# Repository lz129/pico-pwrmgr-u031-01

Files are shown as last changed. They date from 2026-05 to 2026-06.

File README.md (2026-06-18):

# Bluetooth LE based Remote Control Transmitter

What is it? A replacement for broken remote controls used for garage doors and similar purposes. Original equipment is often expensive or completely unobtainium.

Board in housing

## Versions

This document describes rev A. The design and the PCB have some [issues](ISSUES.md) which requires hardware patches on the PCB.

## Hardware

The major part is a [Raspberry Pi Pico W](https://pip-assets.raspberrypi.com/categories/686-raspberry-pi-pico-w/documents/RP-008312-DS-1-pico-w-datasheet.pdf) which is responsible to handle the Bluetooth LE protocol. In order to handle the low power mode of the device an additional microcontroller is used.

The board has been designed with Kicad 10. For details refer to 
[Schematic](bt-rc-tx/schematic.pdf), [PCB](bt-rc-tx/board.pdf), and [PCB-3d](bt-rc-tx/board-3d.png).

Fixes required on the PCB rev A:

* The decoupling capacitor C2 for the microcontroller shall be changed from 100n to 10u. 

* Parallel to C1 an additional electrolyte cap with 470u has to be connected.

* Pin 39 of the Raspberry Pi Pico W has to be disconnected from the +BATT network and a jumper Jx has to be added.

Modifications required on the Raspberry Pi Pico W board:

* Remove R2 and R10 ([power circuit Pico W](images/power-circuit-pico-w.png))

Refer to [images](images) for details.

|Image|Content|
|-----|---|
|[Shipping box](images/shipping-box.jpg)|PCBs as delivered by JLCPCB|
|[Delivered boards](images/delivered-boards.jpg)|PCBs as delivered by JLCPCB|
|[Board unpopulated (front)](images/board-unpopulated-front.jpg)|The unpopulated PCB from the top side|
|[Board unpopulated (back)](images/board-unpopulated-back.jpg)|The unpopulated PCB from the back side|
|[Breadboard setup](images/breadboard-setup.jpg)|The complete design on a breadboard|
|[Debug connections (front)](images/debug-connections-front.jpg)|Populated PCB with debug connections (front)|
|[Debug connections (back)](images/debug-connections-back.jpg)|Populated PCB with debug connections (back)|
|[Board in housing](images/board-in-housing.jpg)|Populated PCB in housing|
|[Final device with batteries](images/final-device-open-box.jpg)|Final device with batteries and open housing|

## Software

### Power Controller

The power controller, a STM32U031 microcontroller handles power up and power down of the Raspberry Pi Pico W, reads keyboard input and controls the LEDs. When completely powered down the transmitter draws only approx. 400nA from the Batteries.

The power controller shuts down the Raspi automatically after a given time (currently 10s) in case the Python script does not complete for whatever reason. The script is able to send a signal over GPIO to the power controller to request an immediate shutdown after its job has finished.

To assist development the power controller can be switched to a debug mode where the Raspberry Pi is powered without timeout. This mode shall be used for Python script development. The mode can be activated by pressing button A for more than 3s. Press button A again to leave the debug mode.

Another debug and test aid is the inhibit power down jumper J4. When active the power controller does not go into power down mode but behaves otherwise identical. Use this jumper when debugging the power controller with ST-Link.

__Note:__ Powering the Raspberry Pi Pico W without timeout is only possible when the jumper J4 is set.

__IMPORTANT:__ The jumper J5 (currently not in rev A design) MUST be removed when connecting the Raspberry Pi Pico W via USB cable to a PC. The cable would supply the power controller with the USB bus voltage of 5V. The power controller however is a 3.3V device which can be damaged in this mode. Instead connect the battery or a lab power supply with 3.3V to supply the power controller.

### Raspberry Pi Pico W

Timing and performance is not critical in the application. Therefore a solution with [Micropython](https://micropython.org) has been chosen. Prebuilt versions for the Raspberry Pi Pico W are available [here](https://micropython.org/download/RPI_PICO_W/). Installation of the Python system can be easily done without tools unsing the UF2 bootloader.

The current python [script](python/garagedoor_central.py) is minimalistic at this time and can be extended as necessary to add additional features.

__Attention__: The sample script has no means for secure communication!

### Connectors and Jumpers

All connectors and jumpers are located on the back side of the PCB.

__J1__ is the connector for the battery. The transmitter is designed to operate on two AA or AAA cells. Both alkali mangan and NiMH cells can be used. Note that the voltage range is dicated by the microcontroller which operates on 1.71 to 3.6 volts and the buck/boost converter in the Raspberry Pi Pico W module which accepts 1.8 to 5.5 volts. Therefore the effective voltage range is between 1.8 and 3.6 volts.

__J3__ is a debug connector to attach a debug probe like the ST-Link from ST Microelectronics. The pin assignment is as follows:

|Pin|Purpose|Comments|
|---|---|---|
|1|GND|
|2|VCC|This is a sense wire for the debug probe to handle the voltage levels correctly. Do not provide power on this pin!|
|3|SWDIO|Serial Wire Debug data I/O 
|4|SWCLK|Serial Wire Debug clock
|5|/Reset|Reset controller

__J5__ jumper to inhibit shutdown. Use it when debugging to avoid debug probe disconnect due to powering down the chip. For normal operation and low power while not using the device the jumper has to be removed.

__Jx__ jumper patched into the rev A design. It disconnects the incoming power from the USB to the microcontroller. __The microcontroller can be damaged when an USB cable is connected to the Raspberry Pi board and the jumper is not removed.__

# BOM

|Reference|Qty|Value|DNP|Exclude from BOM|Exclude from Board|Footprint|Datasheet|
|---|---|-----|---|---|---|---|----|
|A1|1|RaspberryPi_Pico_W||||Module:RaspberryPi_Pico_W_SMD_HandSolder|https://datasheets.raspberrypi.com/picow/pico-w-datasheet.pdf|
|C1|1|47u||||Capacitor_SMD:C_1206_3216Metric|
|C2|1|100n||||Capacitor_SMD:C_0805_2012Metric|
|D3|1|LED1||||LED_THT:LED_D5.0mm|
|D4|1|LED2||||LED_THT:LED_D5.0mm|
|J1|1|Battery 3V||||Connector_PinHeader_2.54mm:PinHeader_1x02_P2.54mm_Horizontal|
|J3|1|SW Debug||||Connector_PinHeader_2.54mm:PinHeader_1x05_P2.54mm_Horizontal|
|J4|1|Inhibit Shutdown||||Connector_PinHeader_2.54mm:PinHeader_1x02_P2.54mm_Horizontal|
|R4,R5|2|2k2||||Resistor_SMD:R_0805_2012Metric|
|SW2|1|BUTTON1||||Button_Switch_THT:SW_PUSH_6mm|
|SW3|1|BUTTON2||||Button_Switch_THT:SW_PUSH_6mm|
|U2|1|STM32U031F8Px||||Package_SO:TSSOP-20_4.4x6.5mm_P0.65mm|https://www.st.com/resource/en/datasheet/stm32u031f8.pdf|
||1|STRAPUBOX 6062 GR Plastic Box 85x65x28mm|||x|Housing|
|Cx|1|470u||||Aluminium Elko radial|

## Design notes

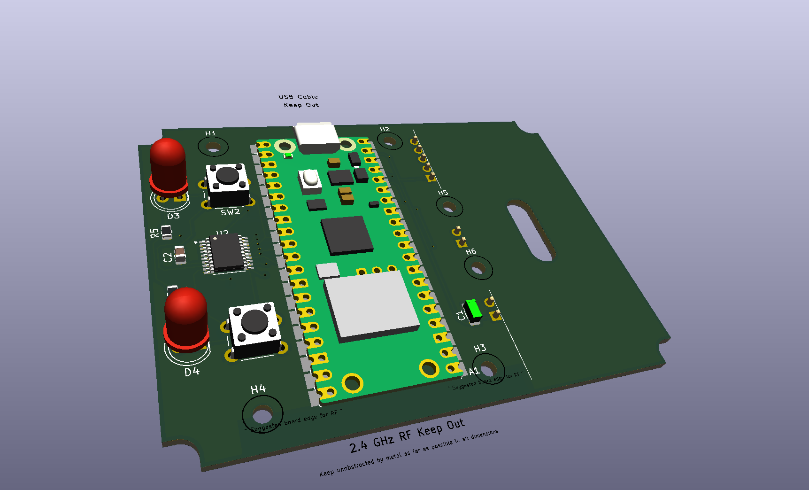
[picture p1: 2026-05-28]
bt-rc-tx/bt-rc-tx.png

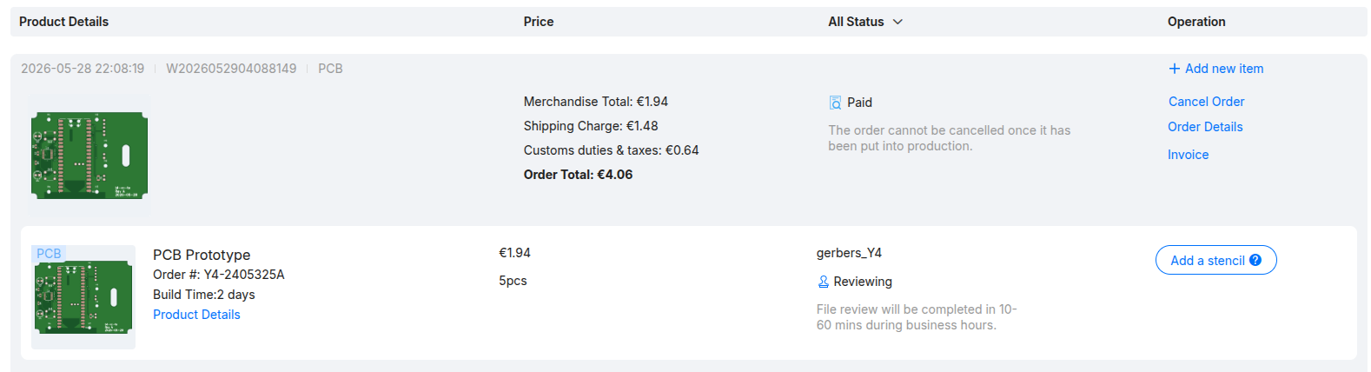
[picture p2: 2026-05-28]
bt-rc-tx/gerbers/ksnip_20260528-221821.png

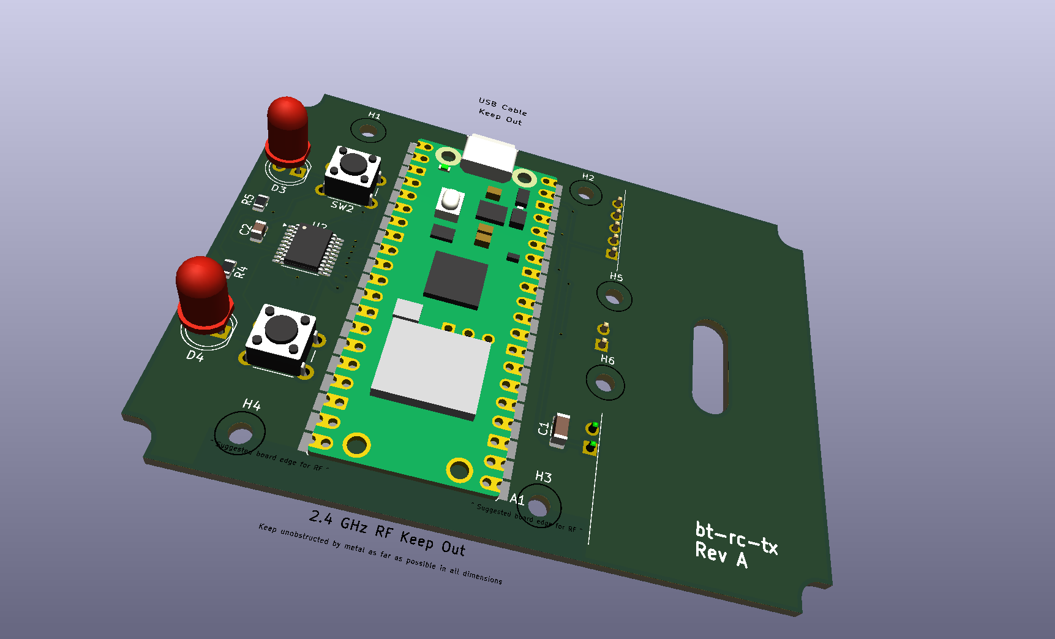
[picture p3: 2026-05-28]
bt-rc-tx/board-3d.png

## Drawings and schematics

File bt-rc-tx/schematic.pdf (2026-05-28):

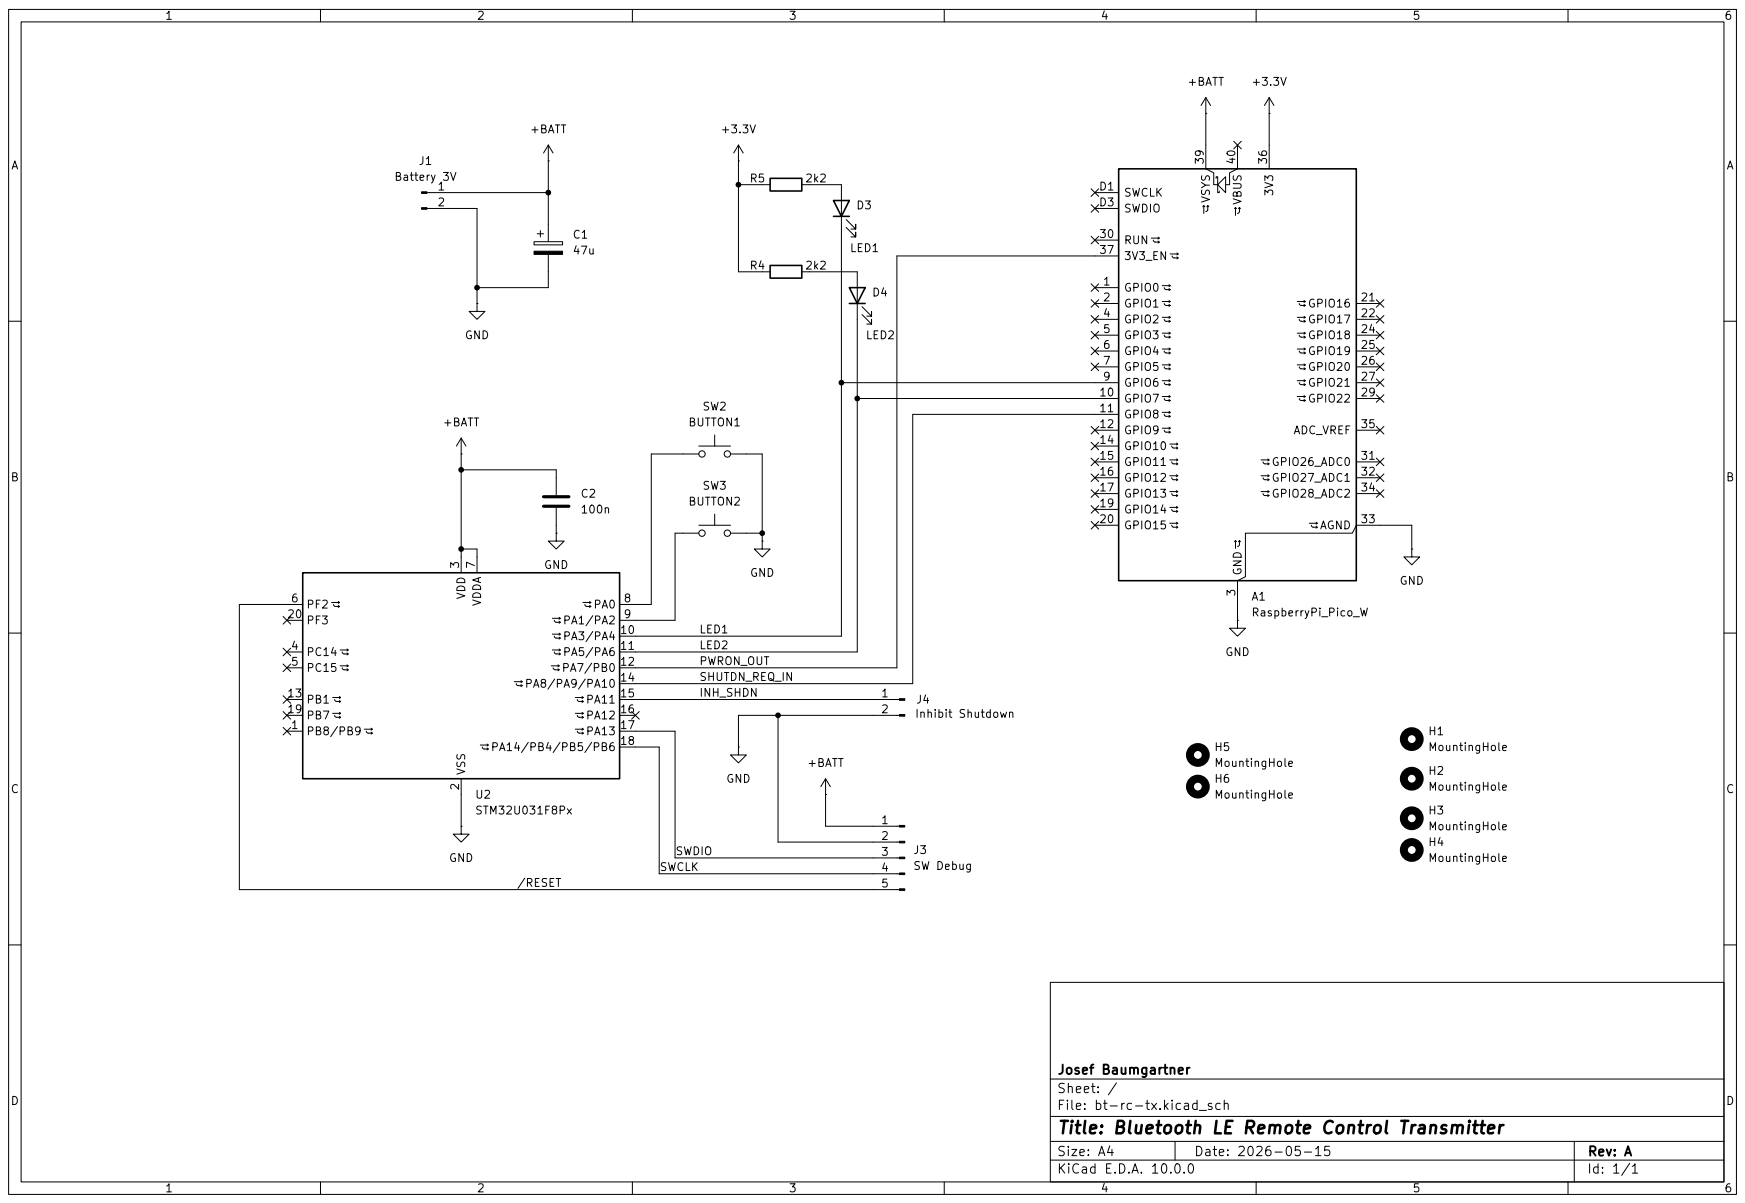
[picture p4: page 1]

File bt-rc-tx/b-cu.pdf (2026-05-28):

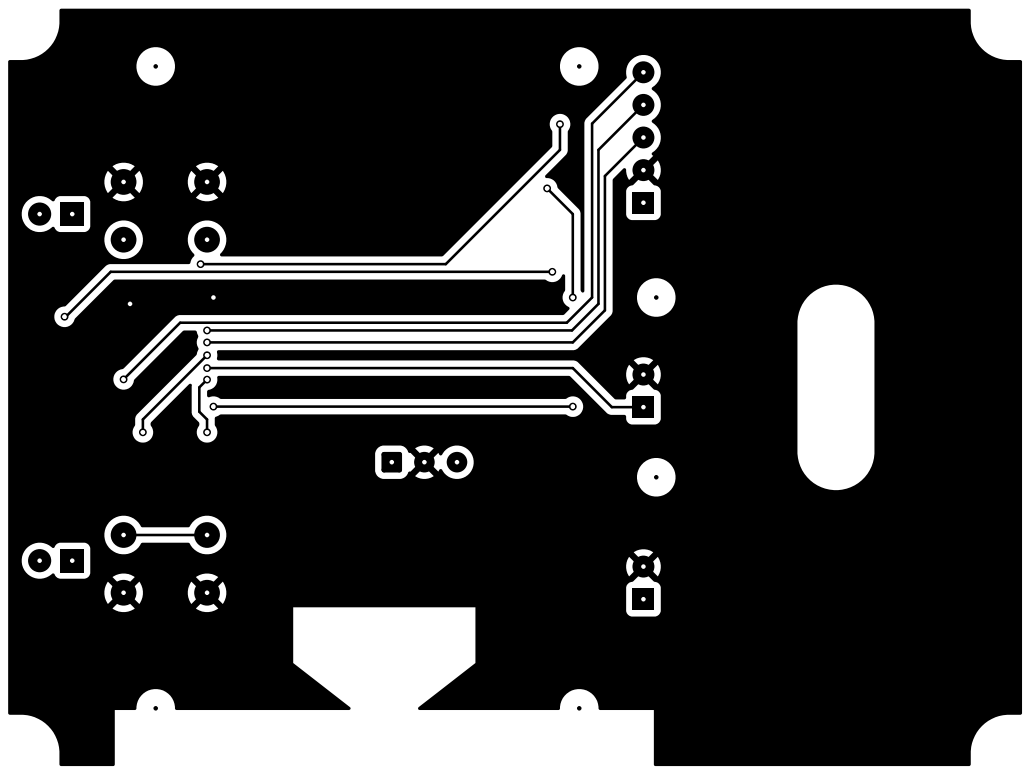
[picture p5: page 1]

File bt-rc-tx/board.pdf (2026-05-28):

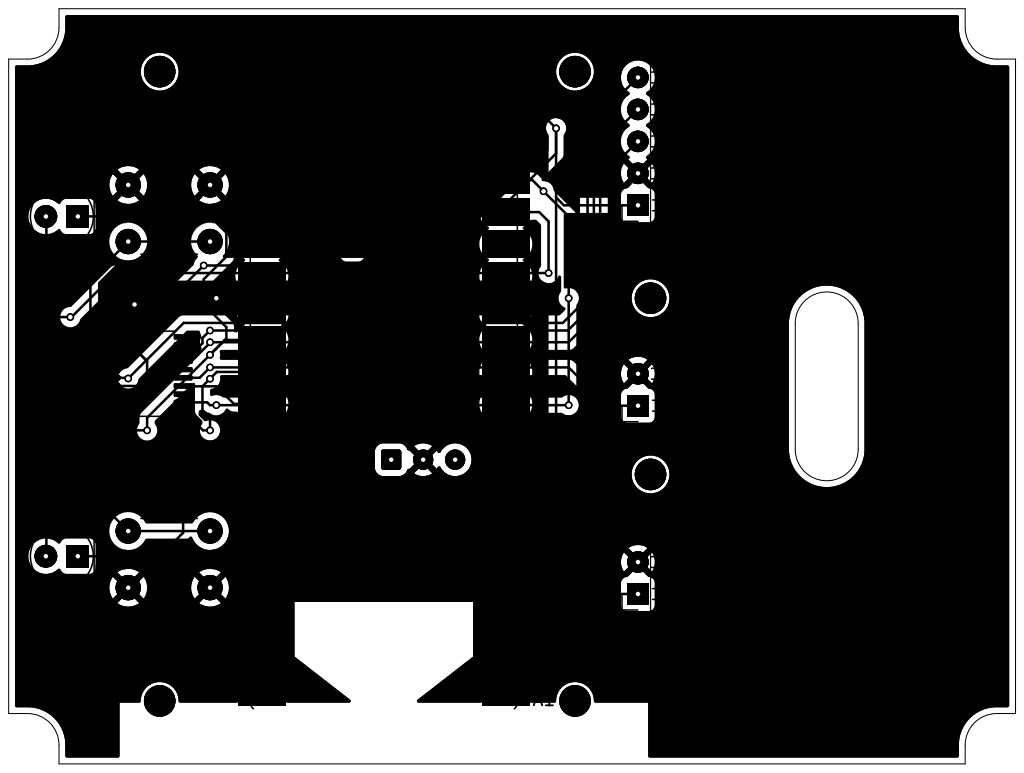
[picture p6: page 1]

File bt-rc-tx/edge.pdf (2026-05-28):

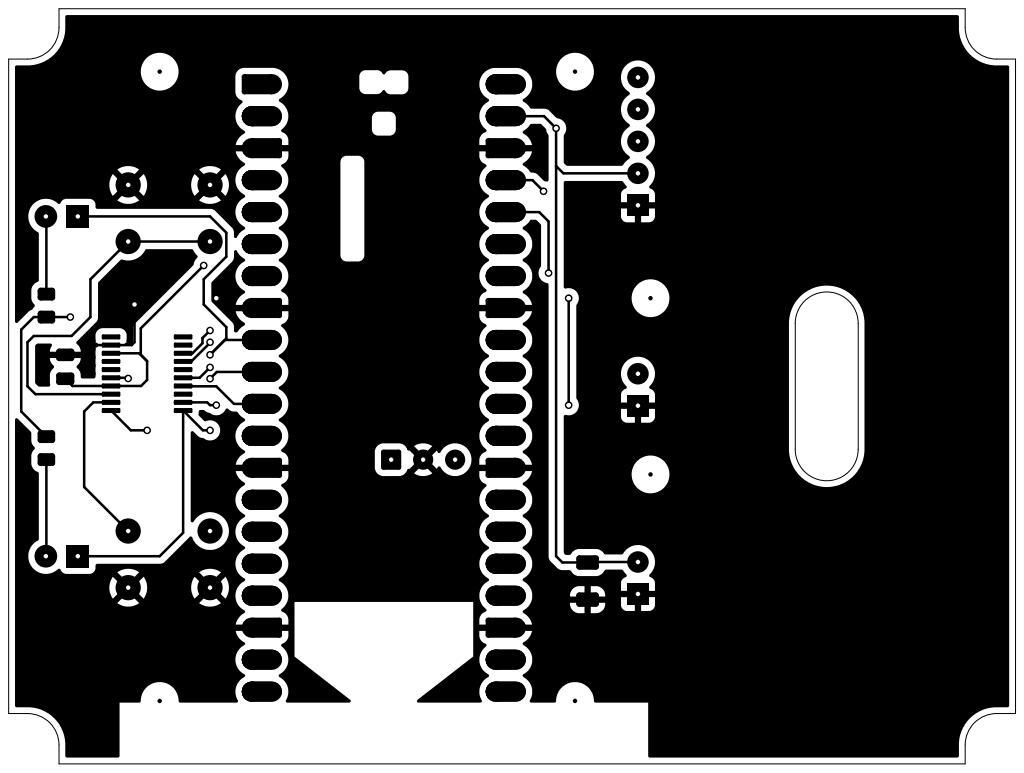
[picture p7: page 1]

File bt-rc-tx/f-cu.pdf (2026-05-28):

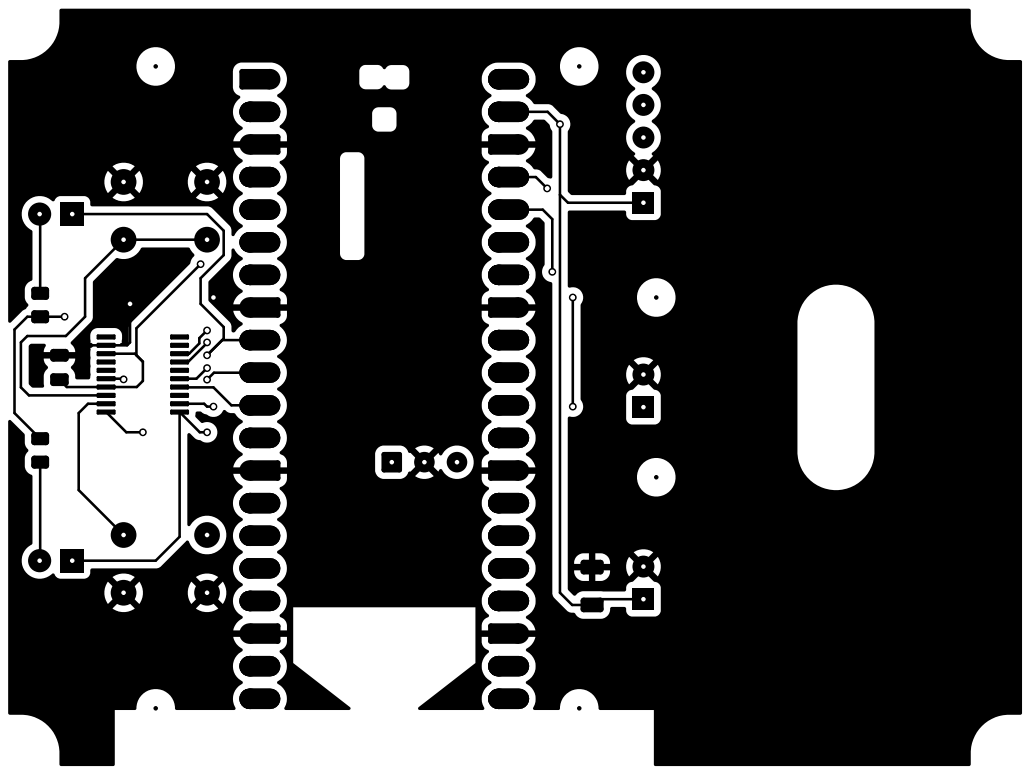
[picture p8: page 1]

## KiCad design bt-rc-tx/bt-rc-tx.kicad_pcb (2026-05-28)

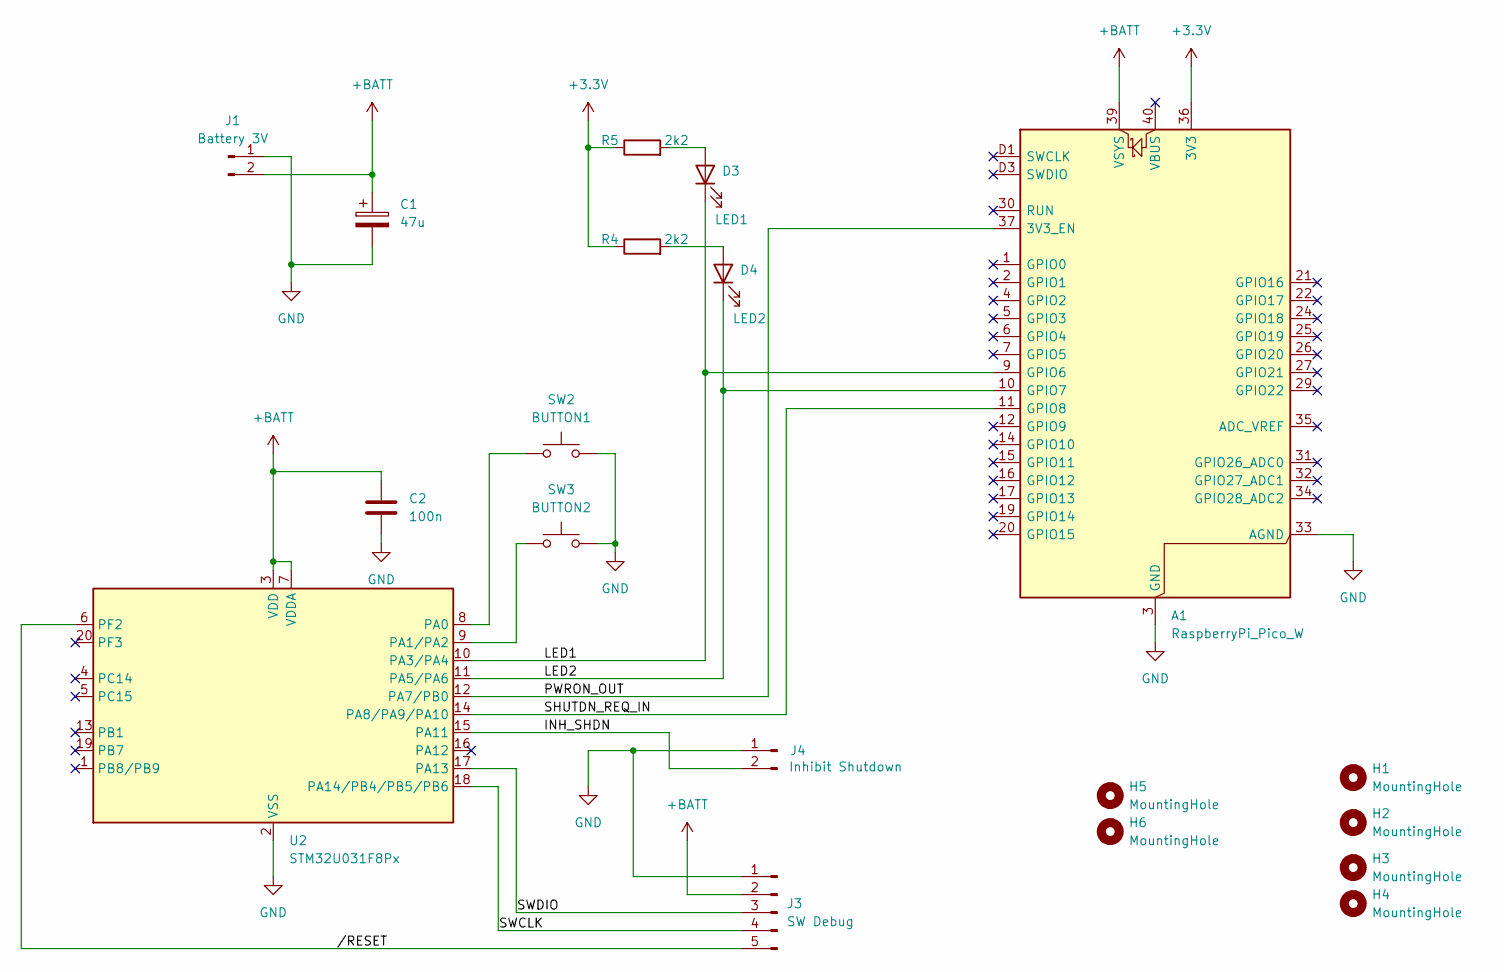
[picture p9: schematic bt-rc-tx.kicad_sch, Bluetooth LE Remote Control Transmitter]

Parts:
A1: RaspberryPi_Pico_W; RaspberryPi_Pico_W_SMD_HandSolder
C1: 47u; C_1206_3216Metric
C2: 100n; C_0805_2012Metric
D3: LED1; LED_D5.0mm
D4: LED2; LED_D5.0mm
H1, H2, H3, H4, H5, H6: MountingHole; MountingHole_2.5mm
J1: Battery 3V; PinHeader_1x02_P2.54mm_Horizontal
J3: SW Debug; PinHeader_1x05_P2.54mm_Horizontal
J4: Inhibit Shutdown; PinHeader_1x02_P2.54mm_Horizontal
R4, R5: 2k2; R_0805_2012Metric
SW2: BUTTON1; SW_PUSH_6mm
SW3: BUTTON2; SW_PUSH_6mm
U2: STM32U031F8Px; TSSOP-20_4.4x6.5mm_P0.65mm

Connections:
+3.3V: A1.36 (3V3), R4.1, R5.1
+BATT: A1.39 (VSYS), C1.1, C2.1, J1.2, J3.2, U2.3 (VDD), U2.7 (VDDA)
/INH_SHDN: J4.2, U2.15 (PA11)
/LED1: A1.9 (GPIO6), D3.1 (K), U2.10 (PA3/PA4)
/LED2: A1.10 (GPIO7), D4.1 (K), U2.11 (PA5/PA6)
/PWRON_OUT: A1.37 (3V3_EN), U2.12 (PA7/PB0)
/SHUTDN_REQ_IN: A1.11 (GPIO8), U2.14 (PA8/PA9/PA10)
/SWCLK: J3.4, U2.18 (PA14/PB4/PB5/PB6)
/SWDIO: J3.3, U2.17 (PA13)
//RESET: J3.5, U2.6 (PF2)
GND: A1.3 (GND), A1.8 (GND), A1.13 (GND), A1.18 (GND), A1.23 (GND), A1.28 (GND), A1.33 (AGND), A1.38 (GND), A1.D2 (GND), C1.2, C2.2, J1.1, J3.1, J4.1, SW2.2, SW3.2, U2.2 (VSS)
unnamed: D3.2 (A), R5.2
unnamed: D4.2 (A), R4.2
unnamed: SW2.1, U2.8 (PA0)
unnamed: SW3.1, U2.9 (PA1/PA2)

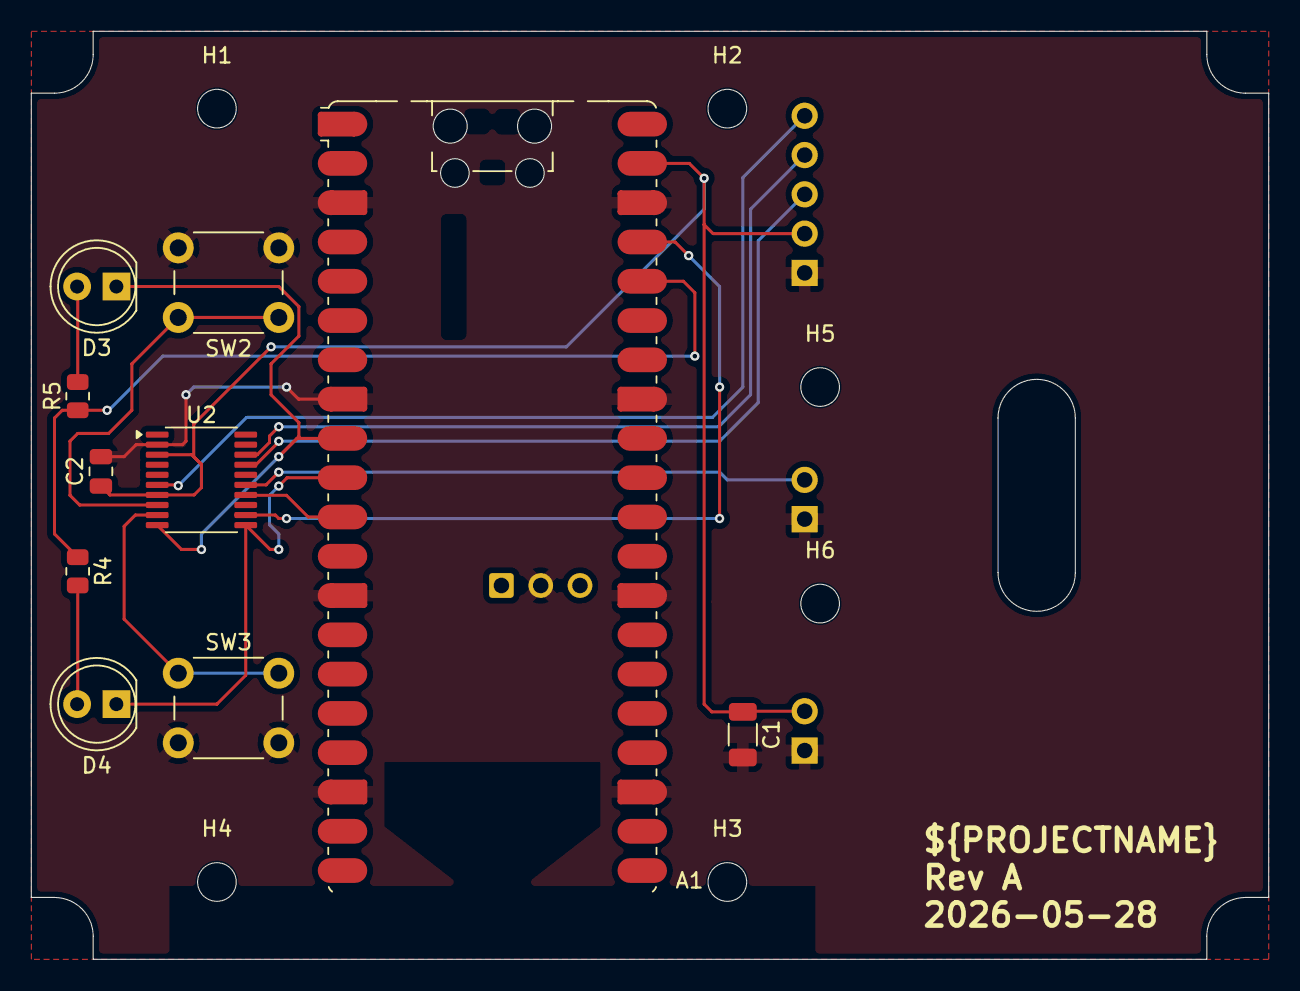
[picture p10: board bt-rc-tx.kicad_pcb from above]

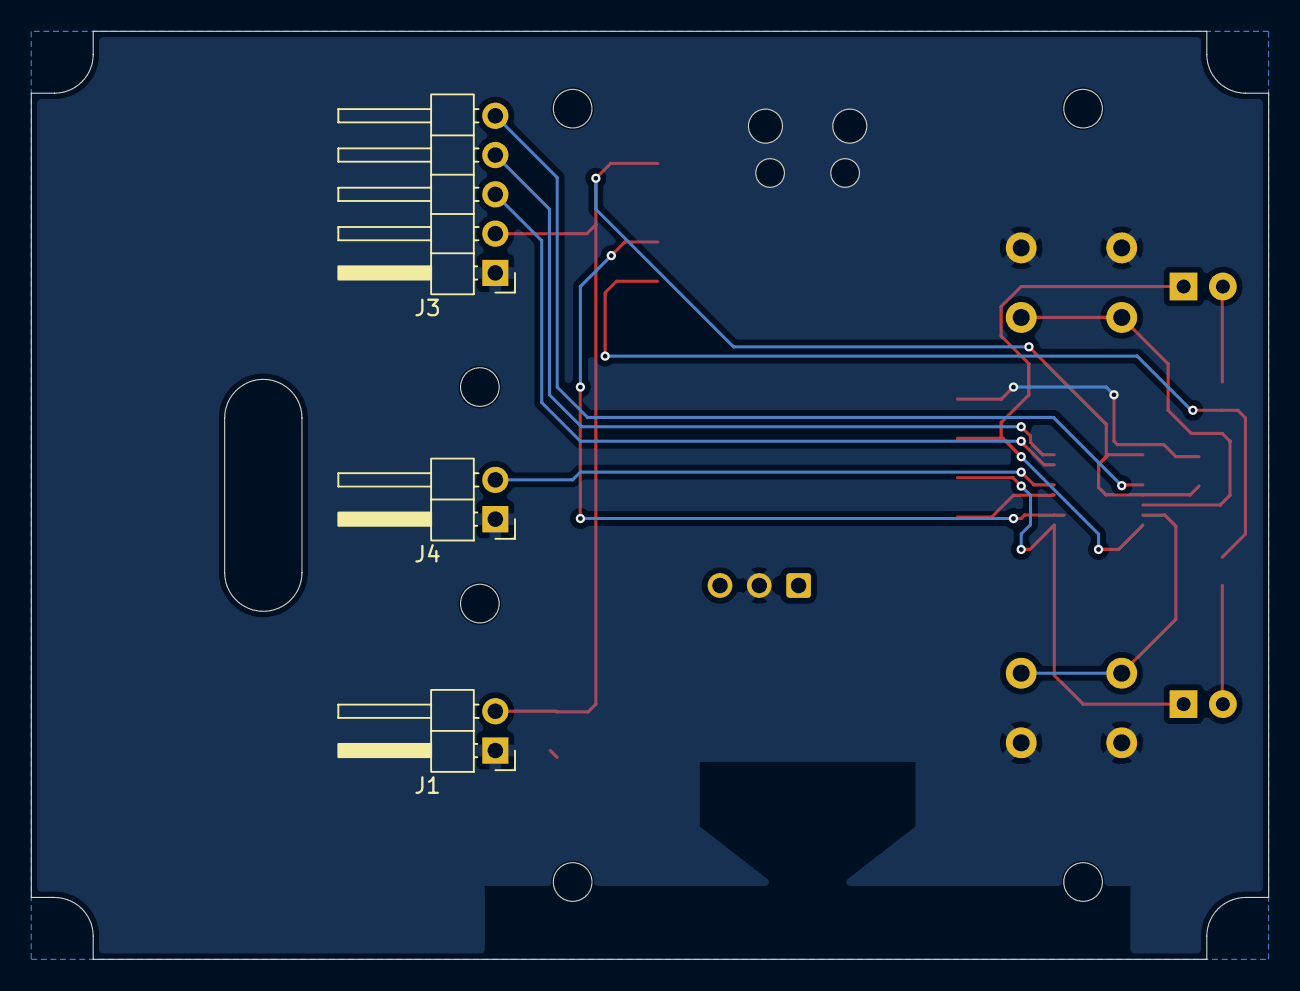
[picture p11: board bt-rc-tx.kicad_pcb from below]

Board: 2 copper layers, 80.0 x 60.0 mm, 19 parts (3 on the bottom side), 15 nets.

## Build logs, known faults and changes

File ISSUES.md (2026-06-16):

# Rev B
(not yet defined)

## Findings

# Rev A

## Findings

* Not all microUSB connectors fit into the Pico USB socket due to a missing cutout in the PCB.
<br>
__Workaround:__ Try to find a suitable USB cable or cut the area in the PCB around the USB socket.

* The VSYS of the Pico is connected to the battery which is necessary when the device is supplied from a 3V battery. With the USB cable attached to the Pico for programming and debugging purposes VSYS is approx. 5V (-0.4V due to serial Schottky diode) which can destroy the power controller STM32U031.
<br>
__Workaround:__ This connection needs to be cut on the board for programming and test purposes and later connected when the device is powered by its batteries. For a new layout a jumper shall be provided.

### SHUTDN_REQ_IN Voltage Levels

A signal on this line is sent from the Pi Pico to the power controller to indicate a request to power down the Pi Pico. The signal is active low, e.g. a falling edge indicates the request.

The GPIO PA8 of the power controller is configured as input with internal pullup resistor. The output GPIO8 of the Pi Pico is configured as open drain output after initialization.

Unfortunately after powerup of the Pi Pico it takes some time until the initiation routine written in Python takes place and configures the port pin as open drain output. Depending on the size of the application (load time) this currently takes about 800ms. During this time the Pi Pico pins are configured as input with pull-down resistors. Both chips has pullup/pulldown resistors with approx. 50kOhms which effectivly results in a voltage about 1.5V. This is an undefined level and may lead to unexpected switching of the input in the power controller. 

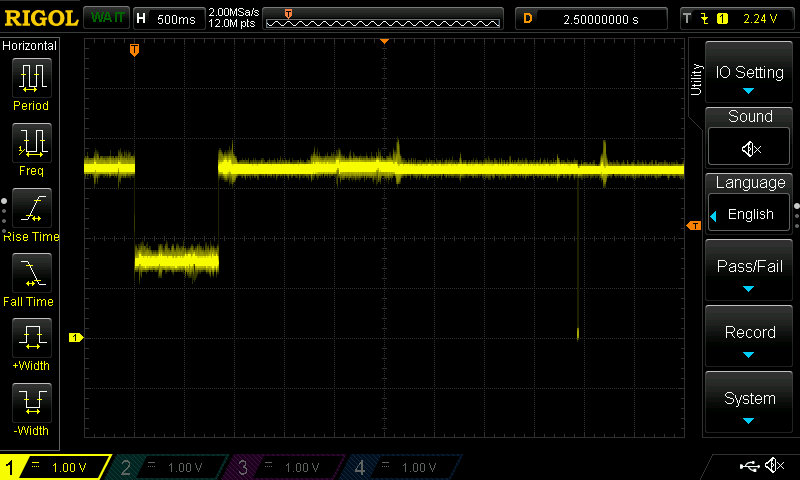
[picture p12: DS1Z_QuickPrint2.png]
[](https://link-to-your-URL/)

At the trigger point the Pi Pico gets powered and activates the pulldown resistors as described. 800ms later the Python initialization routine configures the pin as expected and the voltage level jumps to about 3.3V. 

__Workaround:__ Inhibit (ignore) the signal on this pin for a period of time after powering up the Pi Pico. In the current implementation a time constant of 2s is used.

### Pi Pico Modifications

Remove R2 and R10 from the Pi Pico board. Otherwise the shutdown current will not go under 1uA.

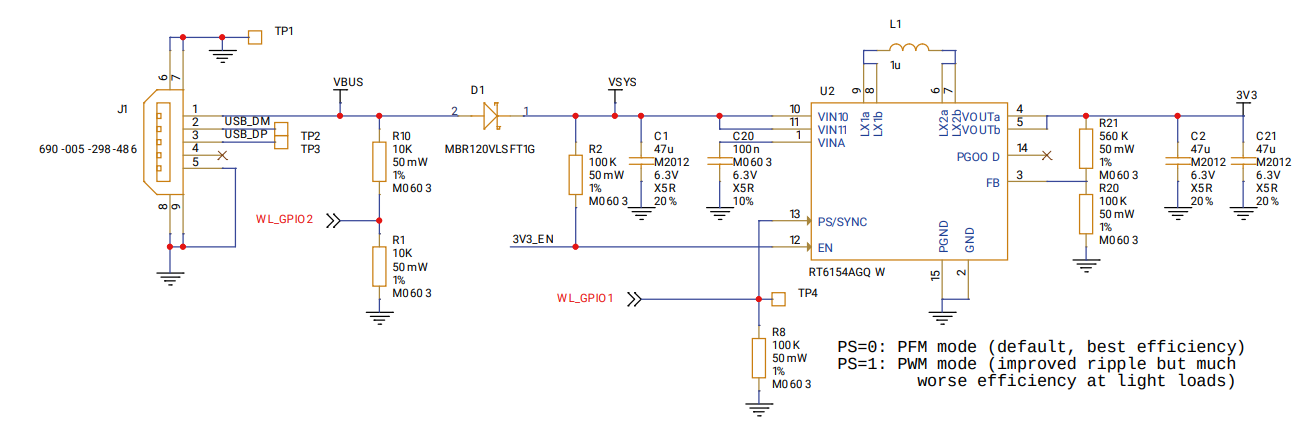
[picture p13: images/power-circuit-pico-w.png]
[](https://link-to-your-URL/)

### Filtering the Supply Voltage

During power up of the Pi Pico it draws excessive current which leads to a short voltage drop on the VCC line of the power controller. In order to circumvent this problem a 470uF capacitor need to be added to the power input.

In addition the filter cap close to the power controller has to be increased from 100nF to 10uF.

### Battery Consumption Calculations

tbd

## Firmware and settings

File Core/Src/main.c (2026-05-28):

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
/* Includes ------------------------------------------------------------------*/
#include "main.h"

/* USER CODE BEGIN Includes */

#include "qpn.h"  /* QP-nano */
#include "bsp.h"  /* Board Support Package */
#include "tasks.h"

/* USER CODE END Includes */


/* USER CODE BEGIN PV */

static QEvt l_testQueue[5];

/* QF_active[] array defines all active object control blocks --------------*/
QActiveCB const Q_ROM QF_active[] = {
    { (QActive *)0, (QEvt *)0, 0U },
    { (QActive *)&AO_Test,  l_testQueue,  Q_DIM(l_testQueue)  }
};

/* USER CODE END PV */

void SystemClock_Config(void);
static void MX_GPIO_Init(void);
/**
  * @brief  The application entry point.
  * @retval int
  */
int main(void)
{

  /* MCU Configuration--------------------------------------------------------*/

  /* Reset of all peripherals, Initializes the Flash interface and the Systick. */
  LL_APB1_GRP1_EnableClock(LL_APB1_GRP1_PERIPH_PWR);
  LL_APB1_GRP2_EnableClock(LL_APB1_GRP2_PERIPH_SYSCFG);

  /* System interrupt init*/
  NVIC_SetPriorityGrouping(NVIC_PRIORITYGROUP_2);

  /* SysTick_IRQn interrupt configuration */
  NVIC_SetPriority(SysTick_IRQn, NVIC_EncodePriority(NVIC_GetPriorityGrouping(),3, 0));

  /* USER CODE BEGIN Init */

    /* instantiate all AOs */
  Test_ctor(&AO_Test);

  QF_init(Q_DIM(QF_active)); /* initialize the QF-nano framework */
  BSP_init();      /* initialize the Board Support Package */

  /* USER CODE END Init */

  /* Configure the system clock */
  SystemClock_Config();

  /* Initialize all configured peripherals */
  MX_GPIO_Init();
  /* Infinite loop */
  /* USER CODE BEGIN WHILE */
  return QF_run(); /* transfer control to QF-nano */
    /* USER CODE END WHILE */

}

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


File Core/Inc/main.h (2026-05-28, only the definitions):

#define BUTTON1_Pin LL_GPIO_PIN_0
#define BUTTON1_GPIO_Port GPIOA
#define BUTTON2_Pin LL_GPIO_PIN_1
#define BUTTON2_GPIO_Port GPIOA
#define LED1_Pin LL_GPIO_PIN_3
#define LED1_GPIO_Port GPIOA
#define LED2_Pin LL_GPIO_PIN_5
#define LED2_GPIO_Port GPIOA
#define PWRON_OUT_Pin LL_GPIO_PIN_7
#define PWRON_OUT_GPIO_Port GPIOA
#define SHUTDN_REQ_IN_Pin LL_GPIO_PIN_8
#define SHUTDN_REQ_IN_GPIO_Port GPIOA
#define INH_SHDN_Pin LL_GPIO_PIN_11
#define INH_SHDN_GPIO_Port GPIOA
#define NVIC_PRIORITYGROUP_0         ((uint32_t)0x00000007) /*!< 0 bit  for pre-emption priority,
#define NVIC_PRIORITYGROUP_1         ((uint32_t)0x00000006) /*!< 1 bit  for pre-emption priority,
#define NVIC_PRIORITYGROUP_2         ((uint32_t)0x00000005) /*!< 2 bits for pre-emption priority,
#define NVIC_PRIORITYGROUP_3         ((uint32_t)0x00000004) /*!< 3 bits for pre-emption priority,
#define NVIC_PRIORITYGROUP_4         ((uint32_t)0x00000003) /*!< 4 bits for pre-emption priority,

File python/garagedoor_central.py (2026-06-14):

from micropython import const
import uasyncio as asyncio
import aioble
import bluetooth
import random
import struct
from machine import Pin
from bluetooth import UUID

_ENV_GARAGEDOOR_SERVICE_UUID = UUID(0xD000)
_ENV_GARAGEDOOR_COMMAND_UUID = UUID(0xD100)
_ENV_GARAGEDOOR_STATUS_UUID  = UUID(0xD101)

status_led = Pin("LED", Pin.OUT)
shutdown_out = Pin(8, Pin.OPEN_DRAIN, value=1)

led1_in = Pin(6, Pin.IN, Pin.PULL_UP)
led2_in = Pin(7, Pin.IN, Pin.PULL_UP)

cmd_characteristic = None

async def find_door_peripheral():
    # Scan for 5 seconds, in active mode, with very low interval/window (to
    # maximise detection rate).
    print("Search for door peripheral")
    async with aioble.scan(5000, interval_us=30000, window_us=30000, active=True) as scanner:
        async for result in scanner:
            if result.name() == "GarageDoorT" and _ENV_GARAGEDOOR_SERVICE_UUID in result.services():
                print("Found peripheral <{}> / {}".format(result.name(), _ENV_GARAGEDOOR_SERVICE_UUID))
                return result.device
    return None

async def central_task():
    device = await find_door_peripheral()
    if not device:
        print("Door peripheral not found")
        return

    try:
        print("Connecting to", device)
        connection = await device.connect()
        print("Connected")
    except asyncio.TimeoutError:
        print("Timeout during connection")
        return

    async with connection:
        
        # Retrieve services and characteristics from remote peripheral
        try:
            global cmd_characteristic
            door_service = await connection.service(_ENV_GARAGEDOOR_SERVICE_UUID)
            cmd_characteristic = await door_service.characteristic(_ENV_GARAGEDOOR_COMMAND_UUID)
            if led1_in.value() == 0:
                await cmd_characteristic.write(b'\x01')
            if led2_in.value() == 0:
                await cmd_characteristic.write(b'\x02')
            print("Characteristic written")
            await asyncio.sleep(2.0)
        except asyncio.TimeoutError:
            print("Timeout discovering services/characteristics")
            return
        print("Close connection, all done well")
        return True


async def main():
    print("-------------- Garage Door Central Application ---------------")
    t2 = asyncio.create_task(central_task())    
    res = await asyncio.gather(t2)
    print("Central application ended", res)
    if res[0]:
        print("Door operation successful")
    else:
        print("Door operation not successful")
    # request shutdown / powerdown of pico    
    shutdown_out.off()


if __name__ == "__main__":
    try:
        asyncio.run(main())
    except KeyboardInterrupt:
        print('Interrupted')
    finally:
        # Clear retained state
        asyncio.new_event_loop()

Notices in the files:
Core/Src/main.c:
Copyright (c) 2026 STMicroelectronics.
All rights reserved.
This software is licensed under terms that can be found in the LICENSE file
